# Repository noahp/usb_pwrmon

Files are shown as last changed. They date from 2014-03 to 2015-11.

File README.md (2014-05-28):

usb_pwrmon
=====
Simple usb port current/voltage measurement with display.

render
=====
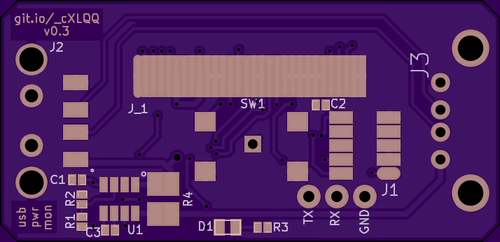
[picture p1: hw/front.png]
front pcb

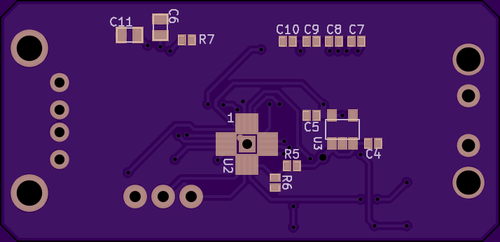
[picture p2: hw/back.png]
back pcb


oled breakout
=====
front pcb
back pcb

comp info
=====

oled
-----
http://www.aliexpress.com/snapshot/276751791.html
http://rusticengineering.com/2010/05/10/oled-0-96-breakout-board-sh1101a-driver/

micro
-----
freescale ksz24/25/26  
http://cache.freescale.com/files/32bit/doc/data_sheet/KL02P32M48SF0.pdf  
http://cache.freescale.com/files/32bit/doc/ref_manual/KL02P32M48SF0RM.pdf

sns resist:
-----
http://www.mouser.com/ProductDetail/Ohmite/LVK12R010DER/?qs=sGAEpiMZZMtlleCFQhR%2fzSLc77HVEnhv2DNaRf6lglA%3d

opamp:
-----
current sense, fixed at 80 gain:
http://www.mouser.com/ProductDetail/Analog-Devices/AD8293G80ARJZ-R7/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
that's a range of 0-4.125A with a shunt resistor of 0.010 Ohms. assuming 16-bit adc (on freescale kl25), ~15 bits per mA.

button:
-----
http://www.mouser.com/Search/ProductDetail.aspx?R=1571621-1virtualkey50660000virtualkey506-1571621-1

usb connectors
-----
[Male A](http://www.mouser.com/ProductDetail/Keystone-Electronics/931/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)  
[Female A](http://www.mouser.com/ProductDetail/Amphenol-Commercial-Products/UE27AC5410H/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)  
[Micro B](http://www.mouser.com/ProductDetail/FCI/10118192-0001LF/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)

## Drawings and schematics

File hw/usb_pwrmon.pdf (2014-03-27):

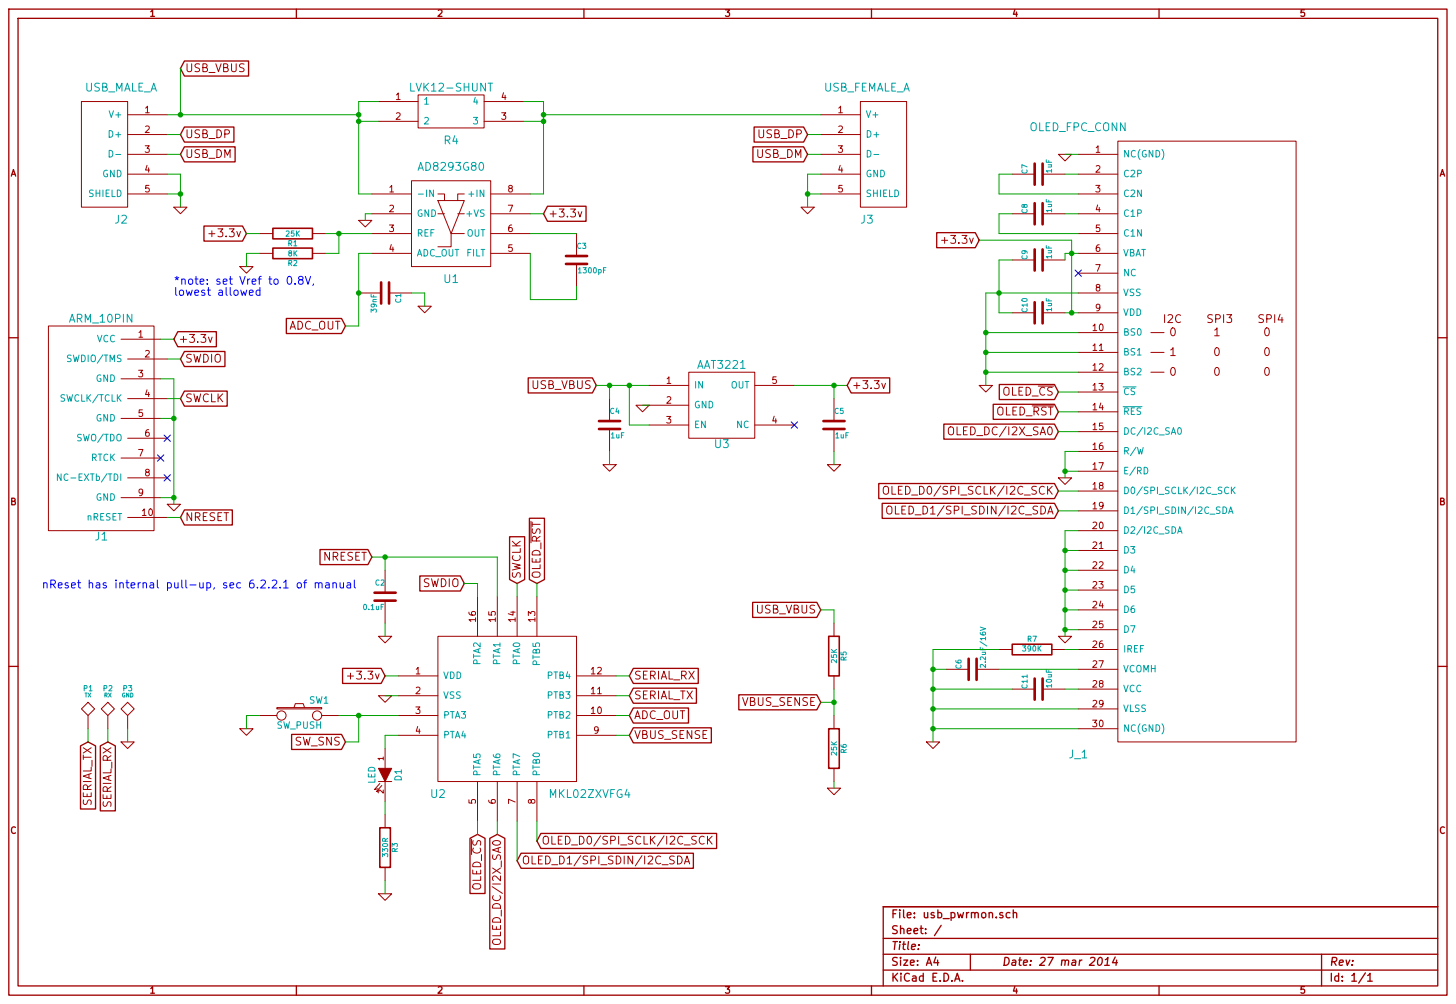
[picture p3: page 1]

*note: set Vref to 0.8V,

nReset has internal pull-up, sec 6.2.2.1 of manual

Id: 1/1 Title: File: usb_pwrmon.sch
Sheet: /

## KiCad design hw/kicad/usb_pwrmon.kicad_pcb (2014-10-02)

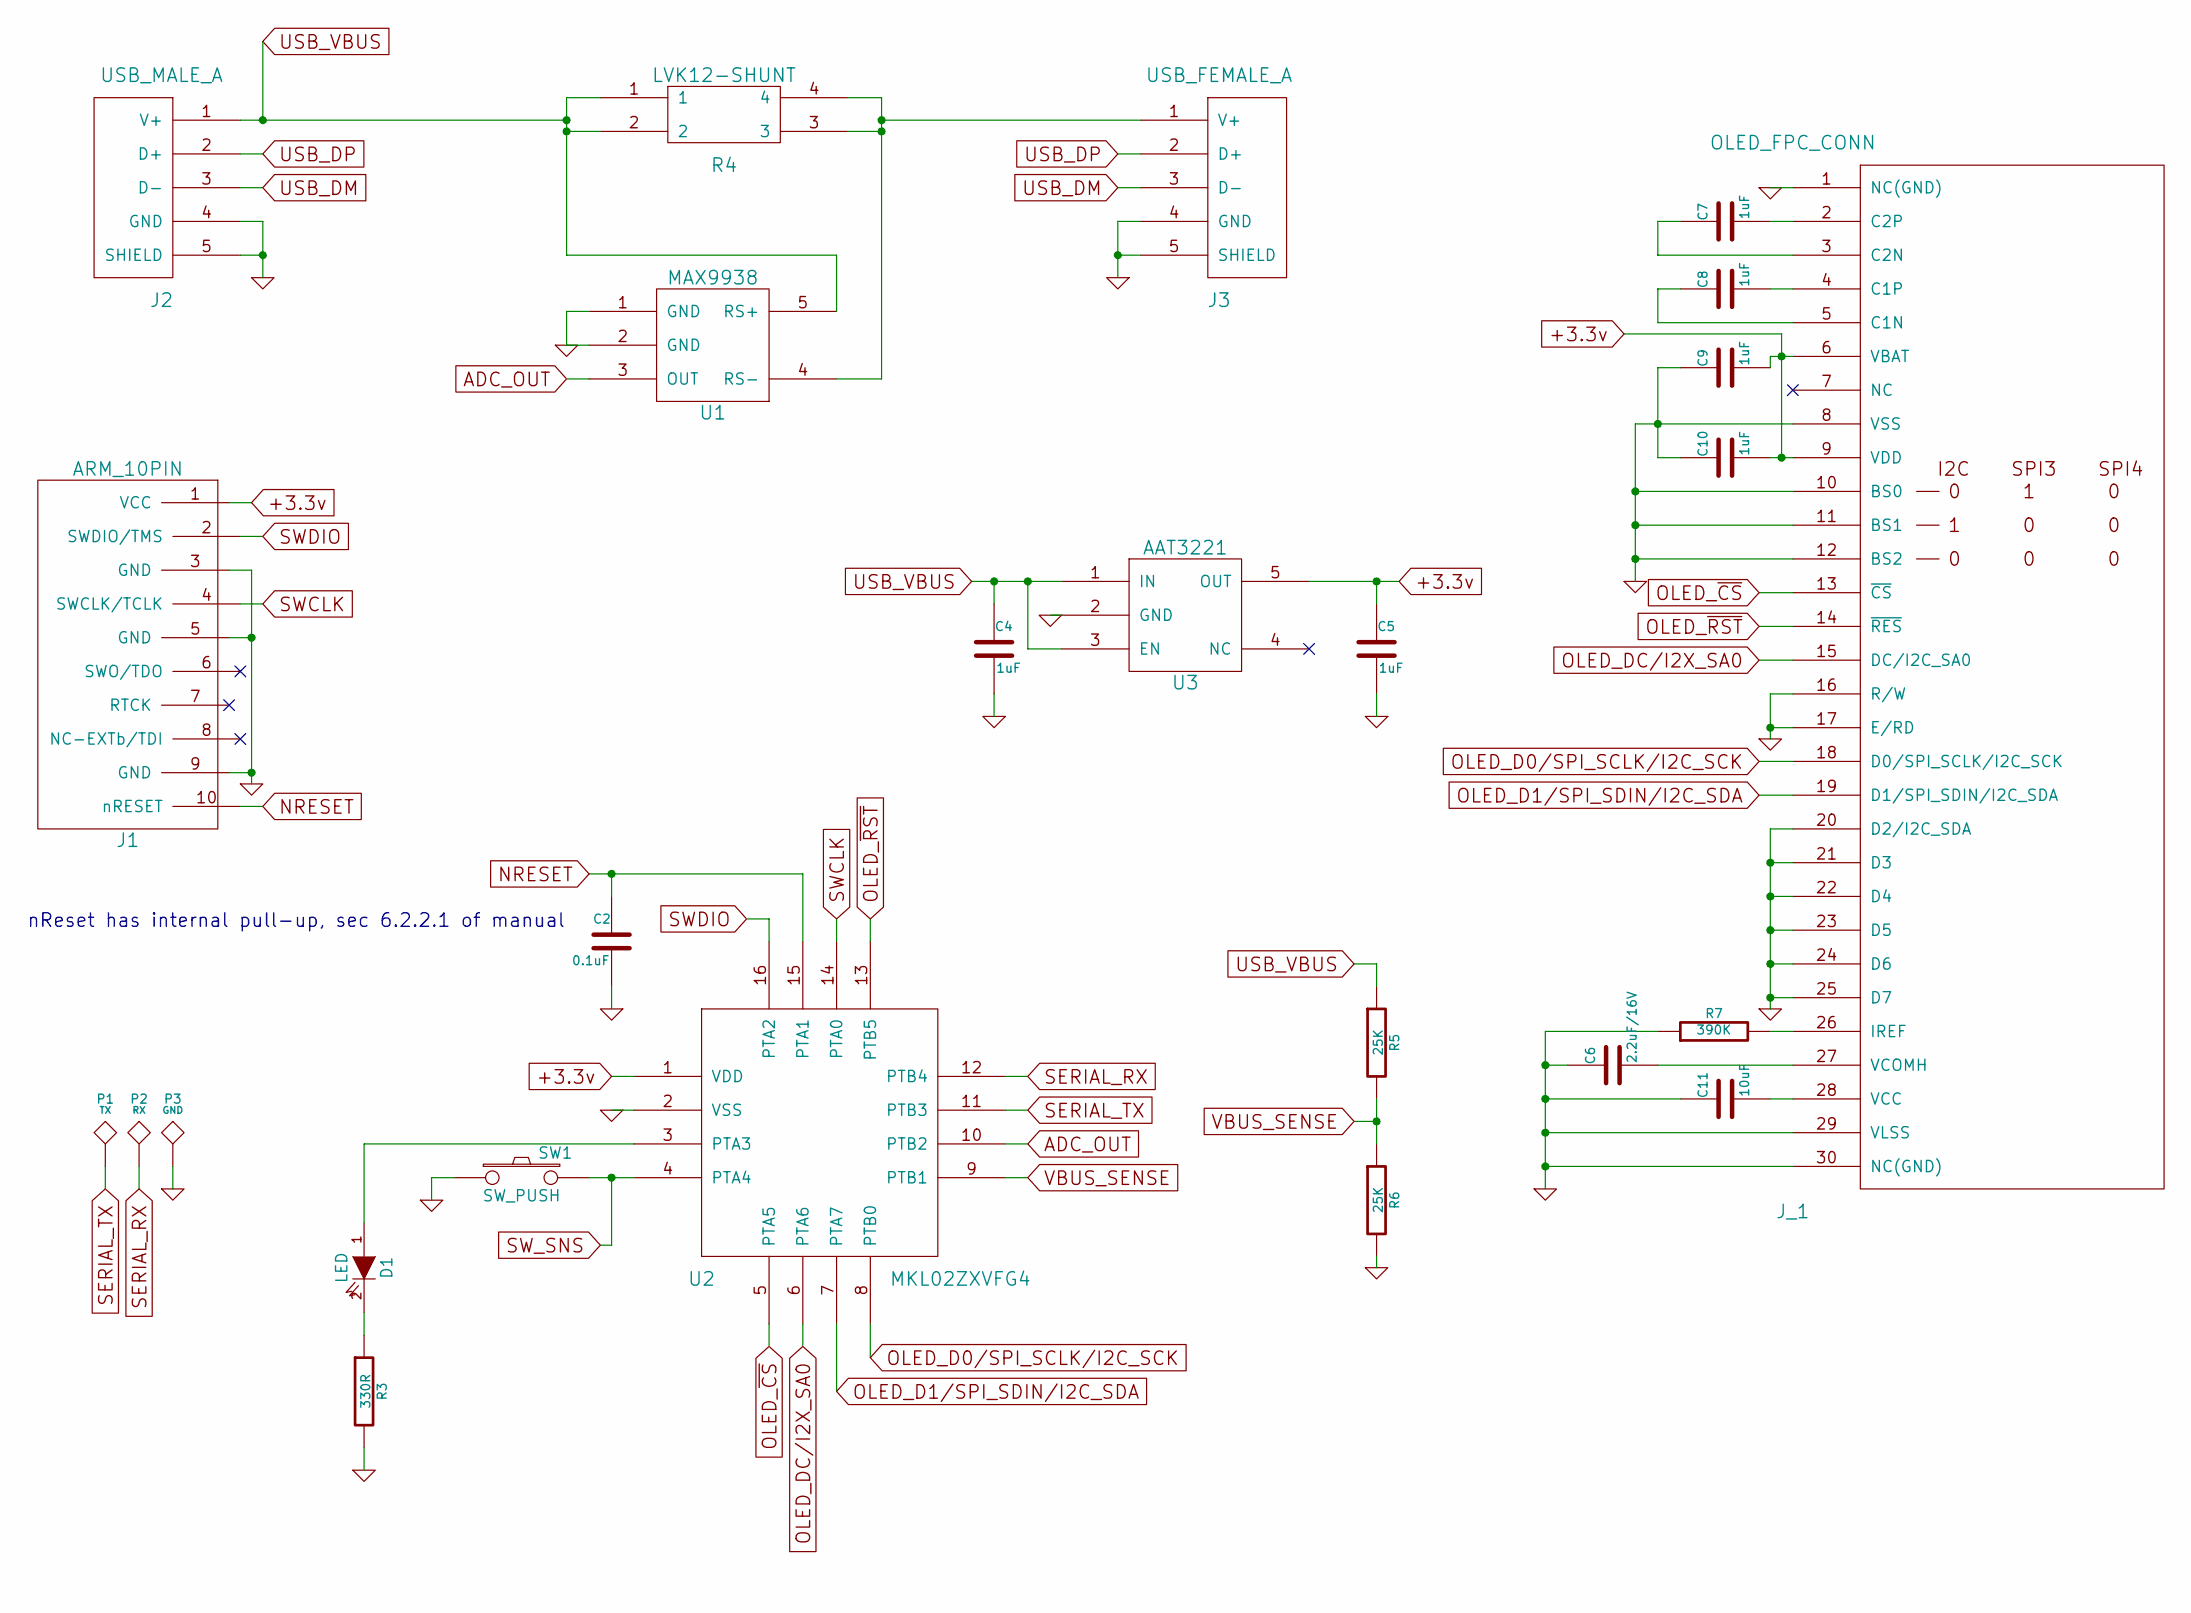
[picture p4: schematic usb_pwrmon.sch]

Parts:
C2: 0.1uF
C4, C5, C7, C8, C9, C10: 1uF
C6: 2.2uF/16V
C11: 10uF
D1: LED
J1: ARM_10PIN
J2: USB_MALE_A
J3: USB_FEMALE_A
J_1: OLED_FPC_CONN
P1: TX
P2: RX
P3: GND
R3: 330R
R4: LVK12-SHUNT
R5, R6: 25K
R7: 390K
SW1: SW_PUSH
U1: MAX9938
U2: MKL02ZXVFG4
U3: AAT3221

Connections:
+3.3v: C5.1, C9.2, C10.2, J1.1 (VCC), J_1.6 (VBAT), J_1.9 (VDD), U2.1 (VDD), U3.5 (OUT)
ADC_OUT: U1.3 (OUT), U2.10 (PTB2)
GND: C2.2, C4.2, C5.2, C6.1, C9.1, C10.1, C11.1, J1.3 (GND), J1.5 (GND), J1.9 (GND), J2.4 (GND), J2.5 (SHIELD), J3.4 (GND), J3.5 (SHIELD), J_1.1 (NC(GND)), J_1.8 (VSS), J_1.10 (BS0), J_1.11 (BS1), J_1.12 (BS2), J_1.16 (R/W), J_1.17 (E/RD), J_1.20 (D2/I2C_SDA), J_1.21 (D3), J_1.22 (D4), J_1.23 (D5), J_1.24 (D6), J_1.25 (D7), J_1.29 (VLSS), J_1.30 (NC(GND)), P3.1, R3.2, R6.2, R7.1, SW1.1, U1.1 (GND), U1.2 (GND), U2.2 (VSS), U3.2 (GND)
unnamed: D1.2 (K), R3.1
unnamed: D1.1 (A), U2.3 (PTA3)
unnamed: J3.1 (V+), R4.3, R4.4, U1.4 (RS-)
unnamed: C8.1, J_1.5 (C1N)
unnamed: C7.1, J_1.3 (C2N)
unnamed: C8.2, J_1.4 (C1P)
unnamed: C7.2, J_1.2 (C2P)
unnamed: C11.2, J_1.28 (VCC)
unnamed: C6.2, J_1.27 (VCOMH)
unnamed: J_1.26 (IREF), R7.2
NRESET: C2.1, J1.10 (nRESET), U2.15 (PTA1)
OLED_D0/SPI_SCLK/I2C_SCK: J_1.18 (D0/SPI_SCLK/I2C_SCK), U2.8 (PTB0)
OLED_D1/SPI_SDIN/I2C_SDA: J_1.19 (D1/SPI_SDIN/I2C_SDA), U2.7 (PTA7)
OLED_DC/I2X_SA0: J_1.15 (DC/I2C_SA0), U2.6 (PTA6)
OLED_~CS: J_1.13 (~CS), U2.5 (PTA5)
OLED_~RST: J_1.14 (~RES), U2.13 (PTB5)
SERIAL_RX: P2.1, U2.12 (PTB4)
SERIAL_TX: P1.1, U2.11 (PTB3)
SWCLK: J1.4 (SWCLK/TCLK), U2.14 (PTA0)
SWDIO: J1.2 (SWDIO/TMS), U2.16 (PTA2)
SW_SNS: SW1.2, U2.4 (PTA4)
USB_DM: J2.3 (D-), J3.3 (D-)
USB_DP: J2.2 (D+), J3.2 (D+)
USB_VBUS: C4.1, J2.1 (V+), R4.1, R4.2, R5.1, U1.5 (RS+), U3.1 (IN), U3.3 (EN)
VBUS_SENSE: R5.2, R6.1, U2.9 (PTB1)

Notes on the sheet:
nReset has internal pull-up, sec 6.2.2.1 of manual

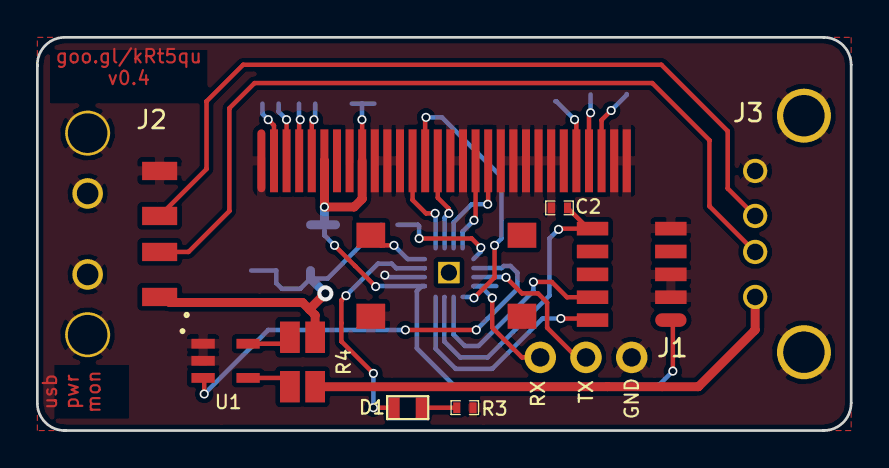
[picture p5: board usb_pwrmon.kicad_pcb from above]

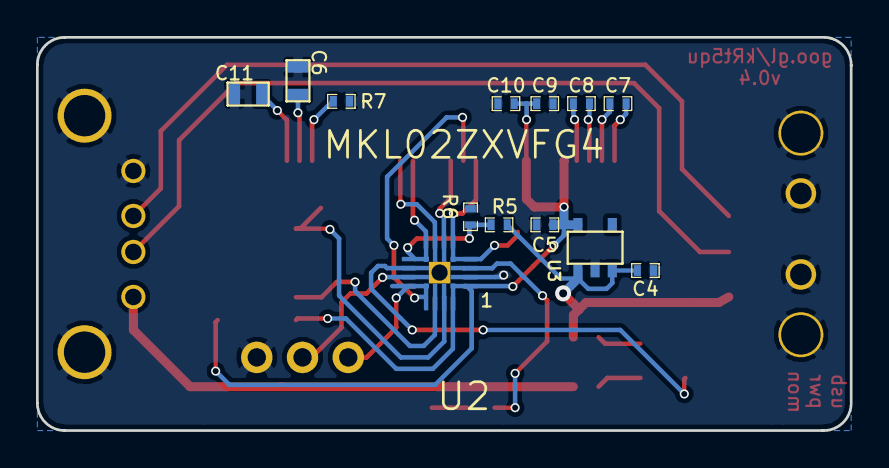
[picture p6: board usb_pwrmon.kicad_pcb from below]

Board: 2 copper layers, 45.2 x 21.8 mm, 26 parts (13 on the bottom side), 28 nets.

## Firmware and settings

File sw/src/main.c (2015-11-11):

#include "MKL02Z4.h"
#include "systick.h"
#include "delay.h"
#include "ssd1306.h"
#include <stdio.h> // sprintf


// need to define _sbrk for sprintf (malloc)
//extern int __end__;
//extern caddr_t _sbrk(int incr);
//extern caddr_t _sbrk(int incr)
//{
//    static unsigned char *heap = NULL;
//    unsigned char *prev_heap;
//
//    if(heap == NULL){
//        heap = (unsigned char *)&__end__;
//    }
//    prev_heap = heap;
//
//    heap += incr;
//
//    return (caddr_t)prev_heap;
//}

static void main_init_io(void)
{
    // init ports
    // disable COP
    SIM_COPC = 0;

    // enable clocks for PORTA
    SIM_SCGC5 |= SIM_SCGC5_PORTA_MASK;

    // set A4 to GPIO
    PORTA_PCR4 = PORT_PCR_MUX(1);

    // set output A4 high (LED on initially)
    GPIOA_PSOR = (1 << 4);

    // set A4 DDR to output
    GPIOA_PDDR |= (1 << 4);

    // set A3 to GPIO- input, pullup enabled
    PORTA_PCR3 = PORT_PCR_MUX(1) | PORT_PCR_PE_MASK | PORT_PCR_PS_MASK;
    GPIOA_PDDR &= ~(1 << 3);
}

static void main_init_uart(void)
{
    // enable clocks for PORTB
    SIM_SCGC5 |= SIM_SCGC5_PORTB_MASK;

    // select uart0 function on b3/b4
    PORTB_PCR3 = PORT_PCR_MUX(3);
    PORTB_PCR4 = PORT_PCR_MUX(3);

    // select MCGFLLCLK for uart0 clock
    SIM_SOPT2 |= SIM_SOPT2_UART0SRC(1);

    // enable uart0 clock
    SIM_SCGC4 |= SIM_SCGC4_UART0_MASK;

    // 115200 baud.
    // set oversampling ratio to 15
    // set baud rate register to 26, yields ~115384 baud, ~1.6% error
    UART0_C4 = (UART0_C4 & (~UART0_C4_OSR_MASK)) | UART0_C4_OSR(15);
    UART0_BDL = (UART0_BDL & (~UART0_BDL_SBR_MASK)) | UART0_BDL_SBR(26);
    UART0_BDH = UART0_BDH_SBR(0);

    // enable tx & rx
    UART0_C2 |= UART0_C2_RE_MASK | UART0_C2_TE_MASK;
}

static void main_init_adc(void)
{
    // enable clocks for PORTB
    SIM_SCGC5 |= SIM_SCGC5_PORTB_MASK;

    // enable ADC clock
    SIM_SCGC6 |= SIM_SCGC6_ADC0_MASK;

    // select ADC on pin B2
    //PORTB_PCR2 = PORT_PCR_MUX(0);   // default
    //PORTB_PCR1 = PORT_PCR_MUX(0);   // default

    // set 12 bit mode, input clock is bus clock / 2 for 12MHz
    ADC0_CFG1 = ADC_CFG1_MODE(1) | ADC_CFG1_ADICLK(1);

    // set high speed mode
    ADC0_CFG2 = ADC_CFG2_ADHSC_MASK;

    // no compare, software trigger, default voltage reference
    ADC0_SC2 = 0;

    // continuous conversion, hardware average enabled 32 samples
    ADC0_SC3 = 0;//ADC_SC3_ADCO_MASK /*| ADC_SC3_AVGE_MASK | ADC_SC3_AVGS(3)*/;

    // select input channel- also, after continuous mode selected, a write to
    // SC1A starts the conversion
    ADC0_SC1A = ADC_SC1_ADCH(4);
}

#define ADC_BUFSIZE 32
static struct {
    uint32_t sum;
    uint32_t time;
    uint16_t avgInt;
    uint32_t avgFrac;
    uint16_t buf[ADC_BUFSIZE];
    uint8_t idx;
} adc_cntrl[2] = {
    {
        .sum = 0,
        .time = 0,
        .idx = 0,
    },
    {
        .sum = 0,
        .time = 0,
        .idx = 0,
    },
};

static void main_adc(void)
{
    static uint8_t chid = 0;
    static uint32_t adcTime = 0;

    // every 10ms take a sample
    if(systick_getMs() - adcTime > 10){
        uint32_t data = ADC0_SC1A;
        if(data & ADC_SC1_COCO_MASK){
            // conversion complete
            // remove oldest sample from sum
            adc_cntrl[chid].idx = (adc_cntrl[chid].idx + 1) % ADC_BUFSIZE;
            adc_cntrl[chid].sum -= adc_cntrl[chid].buf[adc_cntrl[chid].idx];
            // add new sample and compute average
            adc_cntrl[chid].buf[adc_cntrl[chid].idx] = ADC0_RA & 0xFFF;
            adc_cntrl[chid].sum += adc_cntrl[chid].buf[adc_cntrl[chid].idx];
            data = adc_cntrl[chid].sum / ADC_BUFSIZE;

            // compute integer and fractional values
            data *= 330000; // prep to compute voltage
            data /= 4095;   // now in .000001 V units
            adc_cntrl[chid].avgInt = data / 100000;
            adc_cntrl[chid].avgFrac = data - (data / 100000);

            adcTime = systick_getMs();

            // start conversion on the other channel & select it
            if(!chid){
                ADC0_SC1A = ADC_SC1_ADCH(5);
                chid = 1;
            }
            else{
                ADC0_SC1A = ADC_SC1_ADCH(4);
                chid = 0;
            }
        }
    }
}

static void main_led(void)
{
    static uint32_t blinkTime = 0;
//    static uint32_t blinkCount = 0;

    // blink every 250ms
    if(systick_getMs() - blinkTime > 10){
        blinkTime = systick_getMs();
        // toggle
        GPIOA_PTOR = (1 << 4);

//        printf("says who!!!! %d\n", blinkCount);
//        blinkCount++;
    }
}

static void main_uart_tx(uint8_t *pData, uint32_t len)
{
    uint32_t i;

    for(i=0; i<len; i++){
        UART0_D = pData[i];
        while(!(UART0_S1 & UART0_S1_TDRE_MASK));
    }
}

static void main_uart(void)
{
    static struct {
        uint32_t time;
        enum {
            IDLE,
            ACTIVE,
            DONE,
        } state;
    } buttonControl = {
        .state = IDLE,
        .time = 0,
    };
    uint32_t data = GPIOA_PDIR;
    uint32_t charcount;
    uint8_t strBuf[32];

    // report data on button press
    switch(buttonControl.state){
        default:
            buttonControl.state = IDLE;
            // fall through
        case IDLE:
            if((data & (1 << 3)) == 0){
                buttonControl.state = ACTIVE;
                buttonControl.time = systick_getMs();
            }
            break;

        case ACTIVE:
            if((data & (1 << 3)) != 0){
                buttonControl.state = IDLE;
            }
            else if(systick_getMs() - buttonControl.state > 100){
                // send a couple of chars
                charcount = sprintf((char*)strBuf, "%d.%05dA\n\r",
                                    adc_cntrl[0].avgInt, (int)adc_cntrl[0].avgFrac);
                if(charcount){
                    main_uart_tx(strBuf, charcount);
                }

                buttonControl.time = systick_getMs();
                buttonControl.state = DONE;
            }
            break;

        case DONE:
            // back to idle 100ms after release
            if((data & (1 << 3)) != 0){
                if(systick_getMs() - buttonControl.state > 100){
                    buttonControl.state = IDLE;
                }
            }
            break;
    }

    // report data on receiving '?' character
    if(UART0_S1 & UART0_S1_RDRF_MASK){
        data = UART0_D;
        if(data == '?'){
            charcount = sprintf((char*)strBuf, "%d.%05dA\n\r",
                                adc_cntrl[0].avgInt, (int)adc_cntrl[0].avgFrac);
            if(charcount){
                main_uart_tx(strBuf, charcount);
            }
        }
    }
}

static void main_oled(void)
{
    static uint32_t oledTime = 1001;
    char dataString[20];

    if(systick_getMs() - oledTime > 500){
        oledTime = systick_getMs();

        sprintf(dataString, "%d.%05dA",
                adc_cntrl[0].avgInt, (int)adc_cntrl[0].avgFrac);

        ssd1306_setLine(0);
        ssd1306_writeString(dataString, 0);

//        sprintf(dataString, "%d.%05dA",
//                adc_cntrl[0].avgInt, adc_cntrl[0].avgFrac);
    }

//    static unsigned char linenum = 0;
//    static uint32_t oledTime = 1001;
//    static int stringListIdx = 0;
//    char *stringList[] = {
//        "Hello world!",
//        "Another string.",
////        "Lorem ipsum dolor sit amet, consectetur adipisicing elit, sed do eiusmod tempor incididunt ut labore et dolore magna aliqua. Ut enim ad minim veniam, quis nostrud exercitation ullamco laboris nisi ut aliquip ex ea commodo consequat. Duis aute irure dolor in reprehenderit in voluptate velit esse cillum dolore eu fugiat nulla pariatur. Excepteur sint occaecat cupidatat non proident, sunt in culpa qui officia deserunt mollit anim id est laborum.",
//    };
//
//    // blink every 250ms
//    if(systick_getMs() - oledTime > 250){
//        oledTime = systick_getMs();
//        ssd1306_setLine(linenum++);
//        ssd1306_writeString(stringList[stringListIdx], 0);
//        if(++stringListIdx >= 2){
//            stringListIdx = 0;
//        }
//    }
}
extern void  initialise_monitor_handles(void);
int main(void) {
    initialise_monitor_handles();
    // initialize the necessary
    main_init_io();
    main_init_uart();
    main_init_adc();
    ssd1306_init();

    while(1){
        // led task
        main_led();

        // oled task
        main_oled();

        // uart task
        main_uart();

        // adc task
        main_adc();
    }

    return 0;
}

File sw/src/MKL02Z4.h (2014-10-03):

/*
** ###################################################################
**     Processor:           MKL02Z32FM4
**     Compilers:           ARM Compiler
**                          Freescale C/C++ for Embedded ARM
**                          GNU C Compiler
**                          IAR ANSI C/C++ Compiler for ARM
**
**     Reference manual:    KL02RM, Rev.1, Aug 2012
**     Version:             rev. 1.0, 2012-10-04
**
**     Abstract:
**         This header file implements peripheral memory map for MKL02Z4
**         processor.
**
**     Copyright: 1997 - 2012 Freescale, Inc. All Rights Reserved.
**
**     http:                 www.freescale.com
**     mail:                 support@freescale.com
**
**     Revisions:
**     - rev. 1.0 (2012-10-04)
**         Initial version.
**
** ###################################################################
*/

/**
 * @file MKL02Z4.h
 * @version 1.0
 * @date 2012-10-04
 * @brief Peripheral memory map for MKL02Z4
 *
 * This header file implements peripheral memory map for MKL02Z4 processor.
 */


/* ----------------------------------------------------------------------------
   -- MCU activation
   ---------------------------------------------------------------------------- */

/* Prevention from multiple including the same memory map */
#if !defined(MCU_MKL02Z4)  /* Check if memory map has not been already included */
#define MCU_MKL02Z4

/* Check if another memory map has not been also included */
#if (defined(MCU_ACTIVE))
  #error MKL02Z4 memory map: There is already included another memory map. Only one memory map can be included.
#endif /* (defined(MCU_ACTIVE)) */
#define MCU_ACTIVE

#include <stdint.h>

/** Memory map major version (memory maps with equal major version number are
 * compatible) */
#define MCU_MEM_MAP_VERSION 0x0100u
/** Memory map minor version */
#define MCU_MEM_MAP_VERSION_MINOR 0x0000u


/* ----------------------------------------------------------------------------
   -- Interrupt vector numbers
   ---------------------------------------------------------------------------- */

/**
 * @addtogroup Interrupt_vector_numbers Interrupt vector numbers
 * @{
 */

/** Interrupt Number Definitions */
typedef enum {
  INT_Initial_Stack_Pointer    = 0,                /**< Initial stack pointer */
  INT_Initial_Program_Counter  = 1,                /**< Initial program counter */
  INT_NMI                      = 2,                /**< Non-maskable interrupt */
  INT_Hard_Fault               = 3,                /**< Hard fault exception */
  INT_Reserved4                = 4,                /**< Reserved interrupt 4 */
  INT_Reserved5                = 5,                /**< Reserved interrupt 5 */
  INT_Reserved6                = 6,                /**< Reserved interrupt 6 */
  INT_Reserved7                = 7,                /**< Reserved interrupt 7 */
  INT_Reserved8                = 8,                /**< Reserved interrupt 8 */
  INT_Reserved9                = 9,                /**< Reserved interrupt 9 */
  INT_Reserved10               = 10,               /**< Reserved interrupt 10 */
  INT_SVCall                   = 11,               /**< A supervisor call exception */
  INT_Reserved12               = 12,               /**< Reserved interrupt 12 */
  INT_Reserved13               = 13,               /**< Reserved interrupt 13 */
  INT_PendableSrvReq           = 14,               /**< PendSV exception - request for system level service */
  INT_SysTick                  = 15,               /**< SysTick interrupt */
  INT_Reserved16               = 16,               /**< Reserved interrupt 16 */
  INT_Reserved17               = 17,               /**< Reserved interrupt 17 */
  INT_Reserved18               = 18,               /**< Reserved interrupt 18 */
  INT_Reserved19               = 19,               /**< Reserved interrupt 19 */
  INT_Reserved20               = 20,               /**< Reserved interrupt 20 */
  INT_FTFA                     = 21,               /**< FTFA command complete/read collision interrupt */
  INT_LVD_LVW                  = 22,               /**< Low Voltage Detect, Low Voltage Warning */
  INT_Reserved23               = 23,               /**< Reserved interrupt 23 */
  INT_I2C0                     = 24,               /**< I2C0 interrupt */
  INT_I2C1                     = 25,               /**< I2C1 interrupt */
  INT_SPI0                     = 26,               /**< SPI0 interrupt */
  INT_Reserved27               = 27,               /**< Reserved interrupt 27 */
  INT_UART0                    = 28,               /**< UART0 status/error interrupt */
  INT_Reserved29               = 29,               /**< Reserved interrupt 29 */
  INT_Reserved30               = 30,               /**< Reserved interrupt 30 */
  INT_ADC0                     = 31,               /**< ADC0 interrupt */
  INT_CMP0                     = 32,               /**< CMP0 interrupt */
  INT_TPM0                     = 33,               /**< TPM0 fault, overflow and channels interrupt */
  INT_TPM1                     = 34,               /**< TPM1 fault, overflow and channels interrupt */
  INT_Reserved35               = 35,               /**< Reserved interrupt 35 */
  INT_Reserved36               = 36,               /**< Reserved interrupt 36 */
  INT_Reserved37               = 37,               /**< Reserved interrupt 37 */
  INT_Reserved38               = 38,               /**< Reserved interrupt 38 */
  INT_Reserved39               = 39,               /**< Reserved interrupt 39 */
  INT_Reserved40               = 40,               /**< Reserved interrupt 40 */
  INT_Reserved41               = 41,               /**< Reserved interrupt 41 */
  INT_Reserved42               = 42,               /**< Reserved interrupt 42 */
  INT_MCG                      = 43,               /**< MCG interrupt */
  INT_LPTimer                  = 44,               /**< LPTimer interrupt */
  INT_Reserved45               = 45,               /**< Reserved interrupt 45 */
  INT_PORTA                    = 46,               /**< Port A interrupt */
  INT_PORTB                    = 47                /**< Port B interrupt */
} IRQInterruptIndex;

/**
 * @}
 */ /* end of group Interrupt_vector_numbers */


/* ----------------------------------------------------------------------------
   -- Peripheral type defines
   ---------------------------------------------------------------------------- */

/**
 * @addtogroup Peripheral_defines Peripheral type defines
 * @{
 */


/*
** Start of section using anonymous unions
*/

#if defined(__ARMCC_VERSION)
  #pragma push
  #pragma anon_unions
#elif defined(__CWCC__)
  #pragma push
  #pragma cpp_extensions on
#elif defined(__GNUC__)
  /* anonymous unions are enabled by default */
#elif defined(__IAR_SYSTEMS_ICC__)
  #pragma language=extended
#else
  #error Not supported compiler type
#endif
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

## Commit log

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2013-02-24 - use OPA378 from ti as instrumentation amp. - add icsp header test points - basic schematic is done at this point
    [usb_pwrmon.sch]
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2013-03-11 - update to low-side current sense. i think this is about done.
    [usb_pwrmon.sch]
2013-03-19 - add second gain stage and connect to adc - clean up for drc
    [usb_pwrmon.sch]
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2013-10-11 - fix it all up. ready to roll.
    [usb_pwrmon.kicad_pcb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]
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2013-10-11 - fix version #, add schematic pdf
    [usb_pwrmon-B_Cu.gbl, usb_pwrmon-B_Mask.gbs, usb_pwrmon-B_SilkS.gbo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]
2013-10-31 remove gerbers
    Former-commit-id: a41342d3eec4ca8f730e37fc51c6b1e5cd8620a2 [formerly a41342d3eec4ca8f730e37fc51c6b1e5cd8620a2 [formerly 32eedcece8f8c7c22dcb1d825b03550649e028e7]]
    Former-commit-id: 7da5bad7645047f70b0f61dce90124f3a1072d50
    Former-commit-id: e3e3c8545fc2d994e9dd684273e158e0642878b9
    [usb_pwrmon-B_Cu.gbl, usb_pwrmon-B_Mask.gbs, usb_pwrmon-B_SilkS.gbo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]
2013-10-31 add old gerbers to subfolder
    Former-commit-id: 506f4019bd9ce86fdc2229ec208849322aa528c9 [formerly 506f4019bd9ce86fdc2229ec208849322aa528c9 [formerly 5891018200ce89c8d6c42409d1824482201694f4]]
    Former-commit-id: d5a737b1643705d074663e591d51fc8108181a90
    Former-commit-id: 41f91e4560a02bc82f3c82b34b4f3513ce68339e
    [usb_pwrmon-B_Cu.gbl, usb_pwrmon-B_Mask.gbs, usb_pwrmon-B_SilkS.gbo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]
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2013-10-31 new schematic with mkl24/5 and ad8293g80 amp
    Former-commit-id: ac4693991d8abdc5d445cbaefc909b446d0d6420 [formerly ac4693991d8abdc5d445cbaefc909b446d0d6420 [formerly 4a9109472a9407fe635b43a95cd1c65a3b81beb9]]
    Former-commit-id: 1dbed20921111c72b593823ada45a3dbf7315b21
    Former-commit-id: 6b7cd41b20ec488c91ded0642a15e9776eb08592
    [usb_pwrmon.sch]
2013-10-31 working on sch
    Former-commit-id: f8ac0ea2000f7e923b448f6217d0ea35cba610c7 [formerly f8ac0ea2000f7e923b448f6217d0ea35cba610c7 [formerly 29f02dbf4e773d56ffa3c3261b2d66c1b951bd1d]]
    Former-commit-id: c5269c944eb81a72d4da92abec835d3a79df764e
    Former-commit-id: 3b6b85954bec87b50fb528209276810c0470e93d
    [usb_pwrmon.sch]
2013-10-31 pop arm debug header
    Former-commit-id: d5df85ed5a434d3ef5b0c7d2dfbc2d922e464fb3 [formerly d5df85ed5a434d3ef5b0c7d2dfbc2d922e464fb3 [formerly f2c820a7cda0a871eab099a68b0b6fad4a23c513]]
    Former-commit-id: 8dfd089300d51ac9194a1659276579516a26efa6
    Former-commit-id: 3cafe83c497ca93ebd9511251291f78c0a64231a
    [usb_pwrmon.sch]
2013-11-09 - fpc connector
    Former-commit-id: 6685d56f5c7f47c431a70211aba2797cf116a25f [formerly 6685d56f5c7f47c431a70211aba2797cf116a25f [formerly 39fcca6794e6a0a2376122315f6af96ae3c01e4f]]
    Former-commit-id: 3bfaab40e79fdfb916e4c6f7b2db3d4696864c31
    Former-commit-id: dbef93559065cb2be07040512478b7806f2621b6
    [usb_pwrmon.sch]
2013-11-10 - add passives and some connections
    Former-commit-id: 0cbe066add0483a1fb74efe12cbe9abbbee8238b [formerly 0cbe066add0483a1fb74efe12cbe9abbbee8238b [formerly 632aac8206b8db47b8f5b2e04e83e7b3be4b6b11]]
    Former-commit-id: a0e75f49b152e5eca435386ea37dbbfa80a0be74
    Former-commit-id: fe0be35bf74c2a8adf19254a67f5b87cb48fbc1c
    [usb_pwrmon.sch]
2013-11-10 sch done
    Former-commit-id: 013926d8b9e7c5538ecf2a99eebdccff4defd2e5 [formerly 013926d8b9e7c5538ecf2a99eebdccff4defd2e5 [formerly 4d012d6b3e56cf83ea9f75bc49d9e1903af969ce]]
    Former-commit-id: a283419c788d7584cf2356aff2ad82939ffebdc0
    Former-commit-id: ccd28c9c253cd86fd1cc7e996420b0fb18ccec6c
    [usb_pwrmon.sch]
2013-11-10 - start work on pcb
    Former-commit-id: 46d673d80cc2a86cb1cf0198eab2f83ad6e8f989 [formerly 46d673d80cc2a86cb1cf0198eab2f83ad6e8f989 [formerly e6562ca754a2c3bdfaa1edcaa4f370bf0480df17]]
    Former-commit-id: 53930e6f4d9856f6407d59fe0fb9abf5292b8064
    Former-commit-id: 7281a321fa1d9912715cdb41e797318617110904
    [usb_pwrmon.kicad_pcb, usb_pwrmon.sch]
2013-11-13 - some work on pcb
    Former-commit-id: e83c8b7e5bcab94e8fbee646e86a45bac6c6c272 [formerly e83c8b7e5bcab94e8fbee646e86a45bac6c6c272 [formerly 18d4f19c09207a9ca7ec5a495ebeb30e648c26b6]]
    Former-commit-id: 0d1dc90981a9c6c5f6a80205f9128b3a8f60f3f5
    Former-commit-id: cb8426d24d42cf8ed3e902c07038b48ca8d503ca
    [usb_pwrmon.kicad_pcb]
2013-11-13 layout done
    Former-commit-id: 9c344a9a71b15ff48bda0fac1c4203cdbd4489e0 [formerly 9c344a9a71b15ff48bda0fac1c4203cdbd4489e0 [formerly e8f59ff3136515c865a4abd7ded41b9bf546da5e]]
    Former-commit-id: 38cdfd79c84e7dd8fb61e084b98eec9332a8d9f5
    Former-commit-id: 1b2e789e887628c82bd9e890b3a6bb7a9bc0c52a
    [usb_pwrmon.kicad_pcb, usb_pwrmon.sch]
2013-11-13 as ordered
    Former-commit-id: 723d12aa2e927baf709e922beb68eb4c6786b970 [formerly 723d12aa2e927baf709e922beb68eb4c6786b970 [formerly 3f4dc9afe7143e35ff6037357ae27188abc31b63]]
    Former-commit-id: a81fd3ca1cf09aa850dd447895322da6a8cd5efa
    Former-commit-id: 210a18c5bd8d0dae89b912255909798f745396fd
    [usb_pwrmon-B_Cu.gbl, usb_pwrmon-B_Mask.gbs, usb_pwrmon-B_SilkS.gbo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]
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2013-12-11 - fix some maths on the font display
    Former-commit-id: 43f38a7a79f8d09fc3ff691174b222740aaee15a [formerly 43f38a7a79f8d09fc3ff691174b222740aaee15a [formerly a9a17e5aeff2da4bd8c947d958d7f5e33622d333]]
    Former-commit-id: 7d3cdb2b325a709a23d33da27f5e5d3192b3cf9a
    Former-commit-id: 00a1a59bc257ebbc28f50107cd33dbae9b8315d1
    [main.c]
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2014-02-08 - fix labels for usb dp/dm
    Former-commit-id: 9a6132e0c8394671b9c07c581e160ab25a986f3f
    Former-commit-id: d3e44395799e84ef5012f8b20a545457baf59de4
    Former-commit-id: 0f8721ac38f384b7a2c523019ac0d14e291278d0
    [usb_pwrmon.kicad_pcb, usb_pwrmon.sch]
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2014-03-08 - fix some components, switch to smt 10 pin debug header
    Former-commit-id: fe5513d4f7cfa6e60e96780276d93b6a6b08847d
    Former-commit-id: e371d3e6ef20b5cd06e2b546f1efa9134f2f16a7
    Former-commit-id: 2d63e4279259ba7f4e4f789c992275eb97b1c8aa
    [usb_pwrmon.kicad_pcb]
2014-03-18 - replace footprints on pcb
    Former-commit-id: 5cc941f39f571a50f1e83a40c3593a89abae6803
    Former-commit-id: affb5e9e8c4de2429eb32b667997dfb1650dbaf3
    Former-commit-id: c77c17cd257b42edf55da28a0b3895ffc35f362b
    [usb_pwrmon.kicad_pcb, usb_pwrmon.sch]
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2014-05-23 - fix layout with corrected footprint for micro
    [usb_pwrmon-B_Cu.gbl, usb_pwrmon-B_Mask.gbs, usb_pwrmon-B_SilkS.gbo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]
2014-05-23 - fix bad footprint (again?) and finish layout this time
    [usb_pwrmon-B_Cu.gbl, usb_pwrmon-B_Mask.gbs, usb_pwrmon-B_SilkS.gbo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]
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2014-05-29 - flip display, add function ssd1306_setLine
    [main.c]
2014-06-25 - fix pcb- broken mcu footprint for whatever reason. also change to use goo.gl url shortener, git.io fails for some reason.
    [usb_pwrmon-B_Cu.gbl, usb_pwrmon-B_Mask.gbs, usb_pwrmon-B_SilkS.gbo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]
2014-10-02 - update gerbers, fixed (hopefully) mkl02
    [usb_pwrmon-B_Cu.gbl, usb_pwrmon-B_Mask.gbs, usb_pwrmon-B_SilkS.gbo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]
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2014-10-17 - fix compile error
    [main.c]
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
